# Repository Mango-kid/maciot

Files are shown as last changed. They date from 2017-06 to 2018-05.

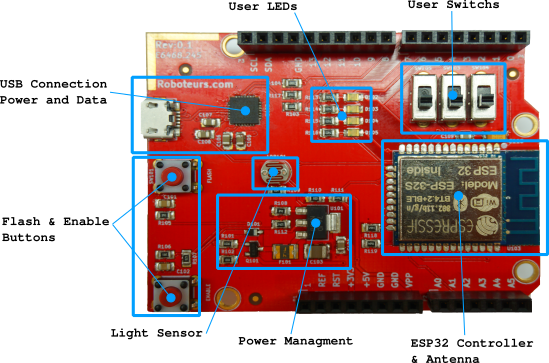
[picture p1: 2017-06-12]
images/layout.png

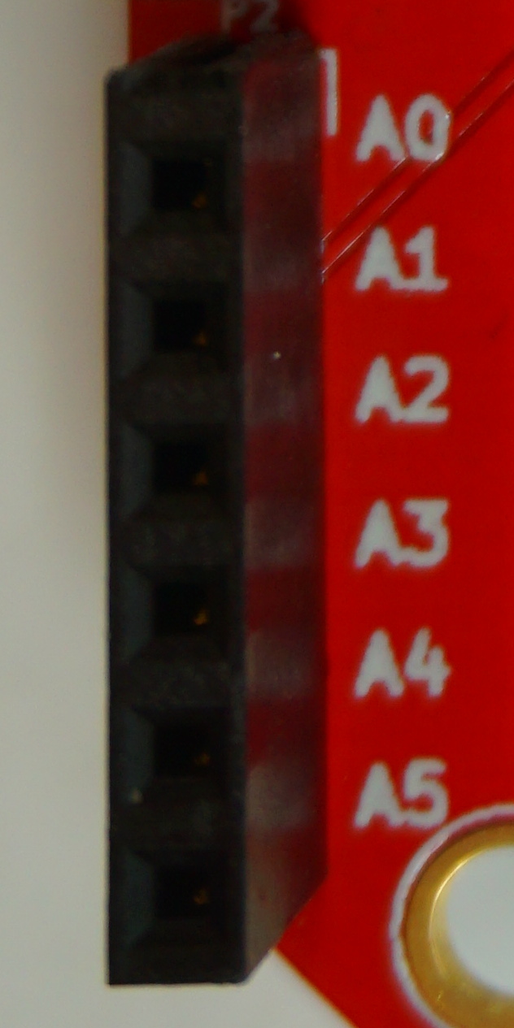
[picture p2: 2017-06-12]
images/pins.JPG

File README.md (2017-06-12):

## Mac-IOT Board

Please check out the [Wiki](https://github.com/Mango-kid/maciot/wiki) for more information on the board design, programming and software setup.  

## Specifications
* bluetooth and(or) wifi capable
* programmable over USB with simple programming IDE
* 4 on board LEDs
* 4 on board switches
* some interactive sensors
* powered by USB or other battery supply
* can use existing Arduino sheild eco-system
***
## License
This project is licensed under the GPLv3 license.

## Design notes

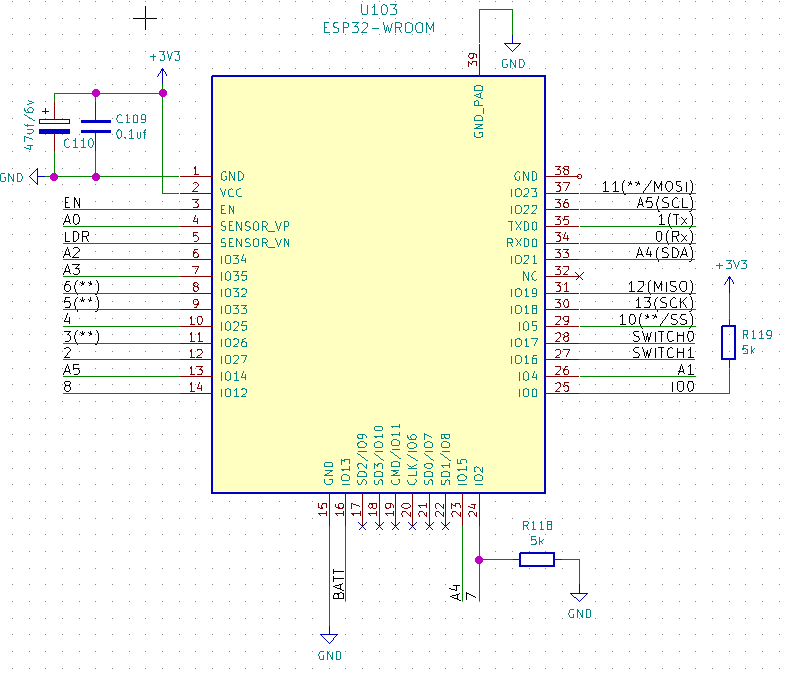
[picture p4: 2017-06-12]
images/sch_esp.png

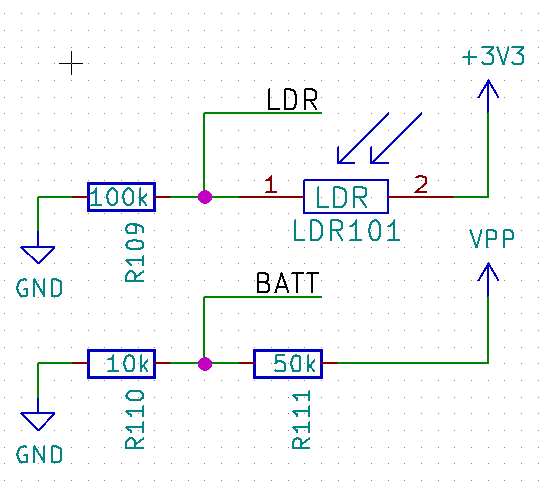
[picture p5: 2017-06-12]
images/sch_sense.png

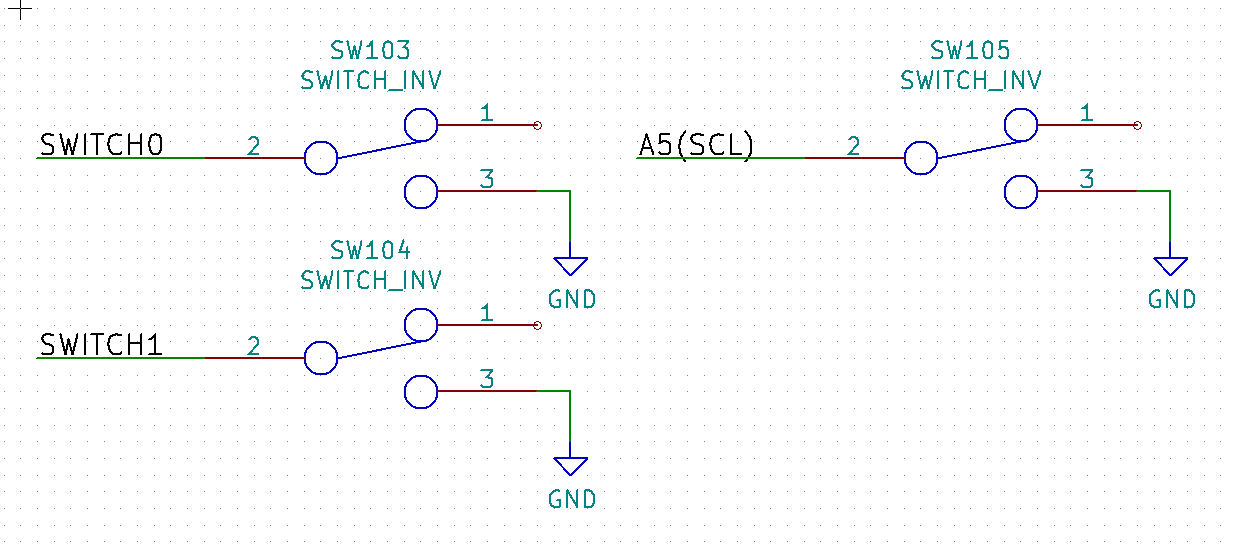
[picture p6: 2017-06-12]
images/sch_switch.png

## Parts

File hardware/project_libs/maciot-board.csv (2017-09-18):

Reference | Value | Footprint | Datasheet | mouser# | digi#
P1 | Power | Socket_Arduino_Uno:Socket_Strip_Arduino_1x08 |  | 474-PRT-09279
P2 | Analog | Socket_Arduino_Uno:Socket_Strip_Arduino_1x06 |  | 474-PRT-09280
P5 | CONN_01X01 | Socket_Arduino_Uno:Arduino_1pin
P6 | CONN_01X01 | Socket_Arduino_Uno:Arduino_1pin
P7 | CONN_01X01 | Socket_Arduino_Uno:Arduino_1pin
P8 | CONN_01X01 | Socket_Arduino_Uno:Arduino_1pin
P4 | Digital | Socket_Arduino_Uno:Socket_Strip_Arduino_1x08 |  | 474-PRT-09279
P3 | Digital | Socket_Arduino_Uno:Socket_Strip_Arduino_1x10 |  | 474-PRT-11376
U101 | LM1117IMPX-ADJ | w_smd_trans:sot223 |  | 926-M1117IMPXADJNOPB
Q101 | Q_PMOS_GDS | w_smd_trans:sot23 |  | 771-PMV48XP215
F101 | FUSE | w_smd_resistors:r_1210 |  | 652-MF-USMF050-2
R102 | 10k | w_smd_resistors:r_0805 |  | ERJ-6GEYJ103V
R101 | 100 | w_smd_resistors:r_0805 |  | ERJ-6ENF1000V
D101 | BAT60 | w_smd_diode:sod323 |  | 726-BAT60AE6327HTSA1
R108 | 390 | w_smd_resistors:r_0805 |  | ERJ-6GEYJ391V
R112 | 240 | w_smd_resistors:r_0805 |  | ERJ-6GEYJ241V
C103 | 10uf | w_smd_cap:c_1210 |  | 77-VJ1210V106ZXJTBC
C104 | 0.1uf | w_smd_cap:c_0805 |  | 81-GCM21BR71H104KA37
U102 | CP2102 | Housings_DFN_QFN:QFN-28-1EP_5x5mm_Pitch0.5mm |  | 634-CP2102-GM
P101 | USB_OTG | w_conn_pc:conn_usb_B_micro_smd |  | 10118192-0001LF
C107 | 0.1uf | w_smd_cap:c_0805 |  | 81-GCM21BR71H104KA40
C108 | 0.1uf | w_smd_cap:c_0805 |  | 81-GCM21BR71H104KA41
C106 | 0.1uf | w_smd_cap:c_0805 |  | 81-GCM21BR71H104KA39
C105 | 0.1uf | w_smd_cap:c_0805 |  | 81-GCM21BR71H104KA38
R117 | 390 | w_smd_resistors:r_0805 |  | ERJ-6GEYJ391V
U103 | ESP32-WROOM | project_foot:ESP32-WROOM
C109 | 0.1uf | w_smd_cap:c_0805 |  | 81-GCM21BR71H104KA42
P102 | TST | Measurement_Points:Measurement_Point_Round-SMD-Pad_Small
P103 | TST | Measurement_Points:Measurement_Point_Round-SMD-Pad_Small
P104 | TST | Measurement_Points:Measurement_Point_Round-SMD-Pad_Small
P105 | TST | Measurement_Points:Measurement_Point_Round-SMD-Pad_Small
P106 | TST | Measurement_Points:Measurement_Point_Round-SMD-Pad_Small
P107 | TST | Measurement_Points:Measurement_Point_Round-SMD-Pad_Small
P108 | TST | Measurement_Points:Measurement_Point_Round-SMD-Pad_Small
P109 | TST | Measurement_Points:Measurement_Point_Round-SMD-Pad_Small
P110 | TST | Measurement_Points:Measurement_Point_Round-SMD-Pad_Small
P111 | TST | Measurement_Points:Measurement_Point_Round-SMD-Pad_Small
P112 | TST | Measurement_Points:Measurement_Point_Round-SMD-Pad_Small
P113 | TST | Measurement_Points:Measurement_Point_Round-SMD-Pad_Small
LDR101 | LDR |  |  |  | PDV-P8103-ND
R110 | 10k | w_smd_resistors:r_0805 |  | ERJ-6GEYJ103V
R111 | 50k | w_smd_resistors:r_0805 |  | ERJ-6ENF4992V
SW101 | FLASH | w_switch:PCB_PUSH |  | 506-FSM4JAH
SW102 | ENABLE | w_switch:PCB_PUSH |  | 506-FSM4JAH
R105 | 390 | w_smd_resistors:r_0805 |  | ERJ-6GEYJ391V
R106 | 390 | w_smd_resistors:r_0805 |  | ERJ-6GEYJ391V
C101 | 10nf | w_smd_cap:c_0805 |  | 81-GRM40X103K50D
C102 | 10nf | w_smd_cap:c_0805 |  | 81-GRM40X103K50D
D102 | LED | w_smd_leds:Led_0805 |  | 604-AP2012YD
R113 | 390 | w_smd_resistors:r_0805 |  | ERJ-6GEYJ391V
D103 | LED | w_smd_leds:Led_0805 |  | 604-AP2012YD
R114 | 390 | w_smd_resistors:r_0805 |  | ERJ-6GEYJ391V
D104 | LED | w_smd_leds:Led_0805 |  | 604-AP2012YD
R115 | 390 | w_smd_resistors:r_0805 |  | ERJ-6GEYJ391V
D105 | LED | w_smd_leds:Led_0805 |  | 604-AP2012YD
R116 | 390 | w_smd_resistors:r_0805 |  | ERJ-6GEYJ391V
SW103 | SWITCH_INV | project_foot:OS102011MS2QN1 Slide Switch |  | 611-OS102011MS2QN1
R118 | 5k | w_smd_resistors:r_0805 |  | ERJ-6ENF4991V
R119 | 5k | w_smd_resistors:r_0805 |  | ERJ-6ENF4991V
SW104 | SWITCH_INV | project_foot:OS102011MS2QN1 Slide Switch |  | 611-OS102011MS2QN1
R107 | 12k | w_smd_resistors:r_0805 |  | ERJ-6GEYJ123V
SW105 | SWITCH_INV | project_foot:OS102011MS2QN1 Slide Switch |  | 611-OS102011MS2QN1
R103 | 0 | w_smd_resistors:r_0805 |  | ERJ-6GEY0R00V
R104 | 0 | w_smd_resistors:r_0805 |  | ERJ-6GEY0R00V
C110 | 47uf/6v | w_smd_cap:c_1206 |  | TAJA476K006SNJV
FD1 | TEST_1P | Fiducials:Fiducial_1mm_Dia_2.54mm_Outer_CopperTop
FD2 | TEST_1P | Fiducials:Fiducial_1mm_Dia_2.54mm_Outer_CopperTop
FD3 | TEST_1P | Fiducials:Fiducial_1mm_Dia_2.54mm_Outer_CopperTop
D1 | LED | w_smd_leds:Led_0805 |  | 604-AP2012YD
R1 | 390 | w_smd_resistors:r_0805 |  | ERJ-6GEYJ391V
R2 | 0 | w_smd_resistors:r_0805 |  | ERJ-6GEY0R00V
R3 | 10k | w_smd_resistors:r_0805 |  | ERJ-6GEYJ103V

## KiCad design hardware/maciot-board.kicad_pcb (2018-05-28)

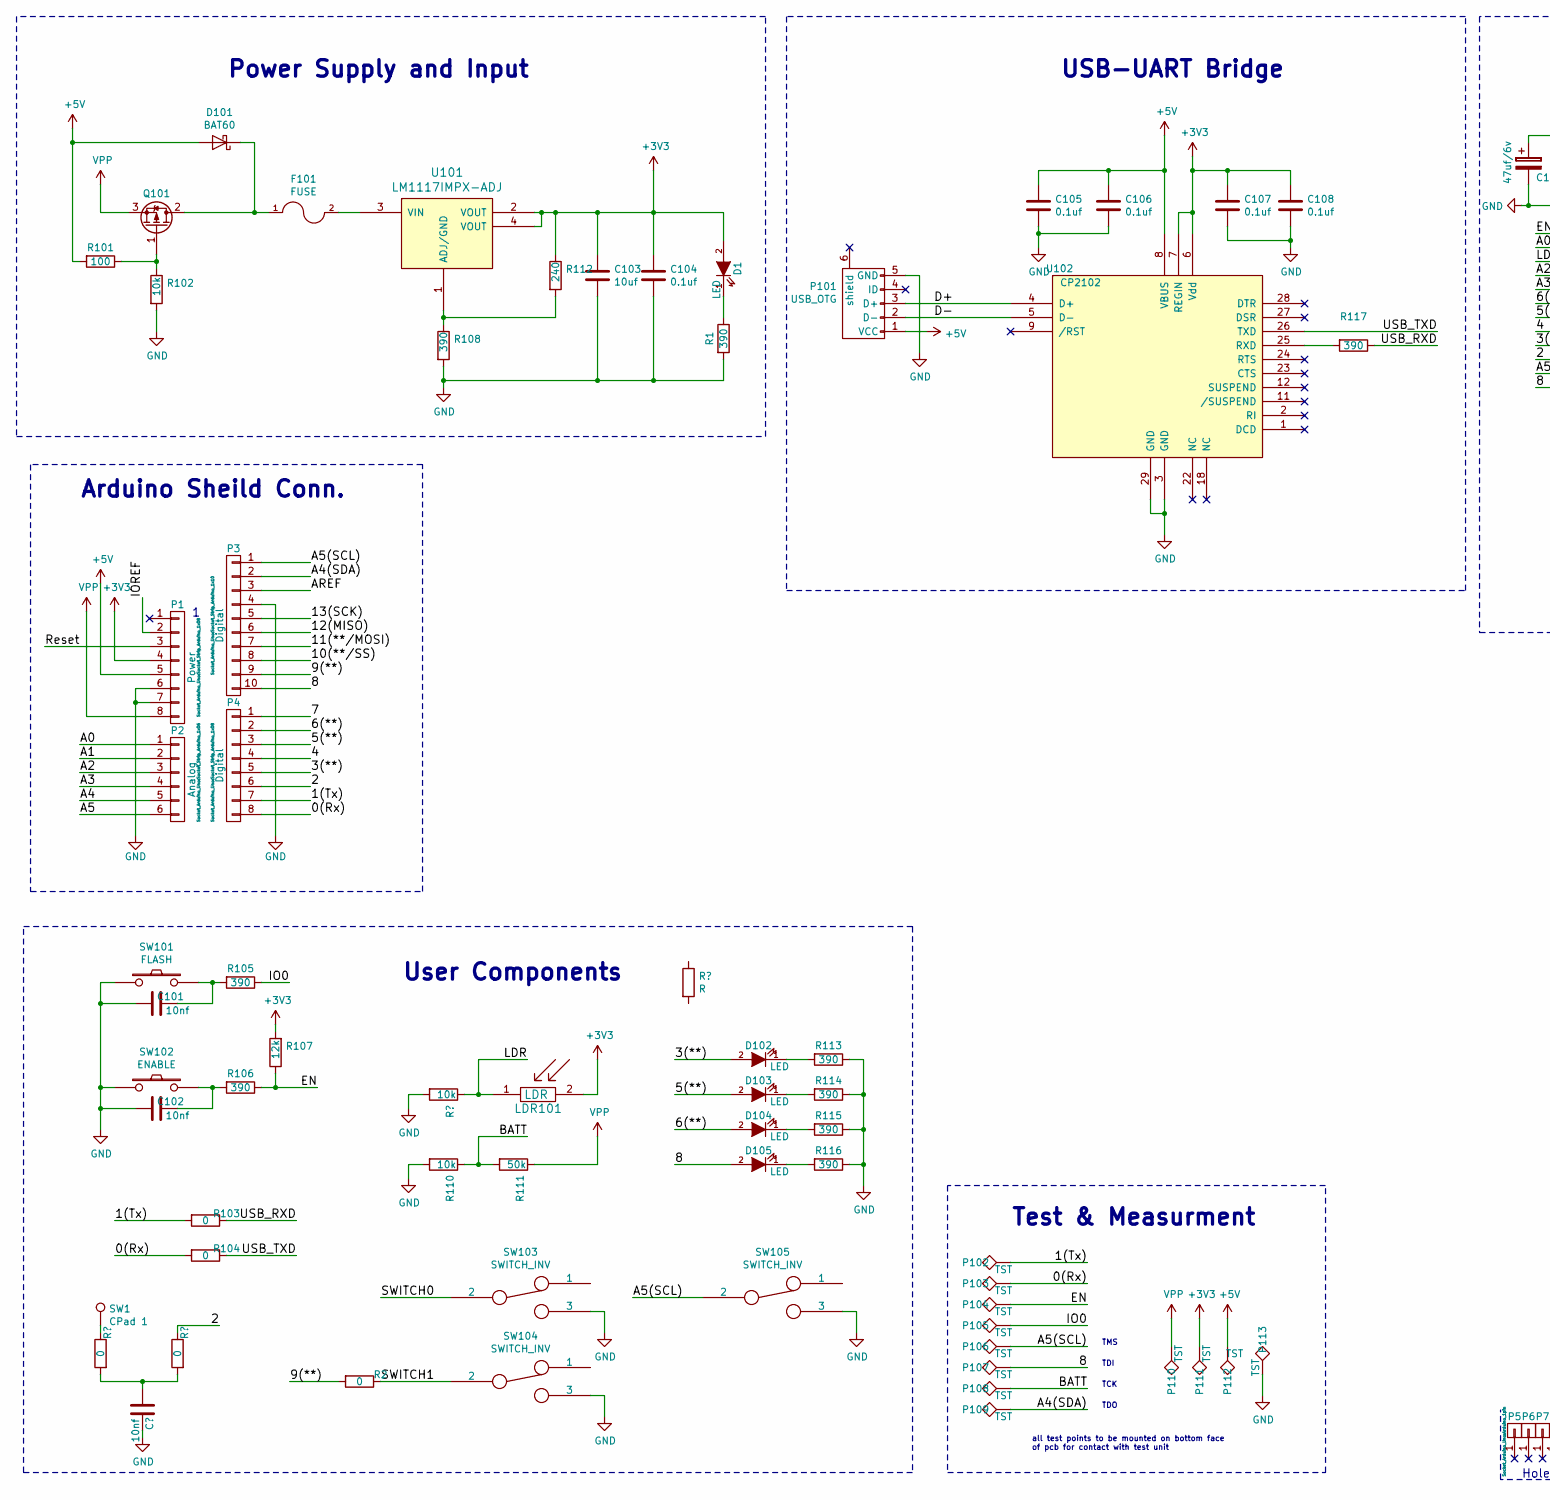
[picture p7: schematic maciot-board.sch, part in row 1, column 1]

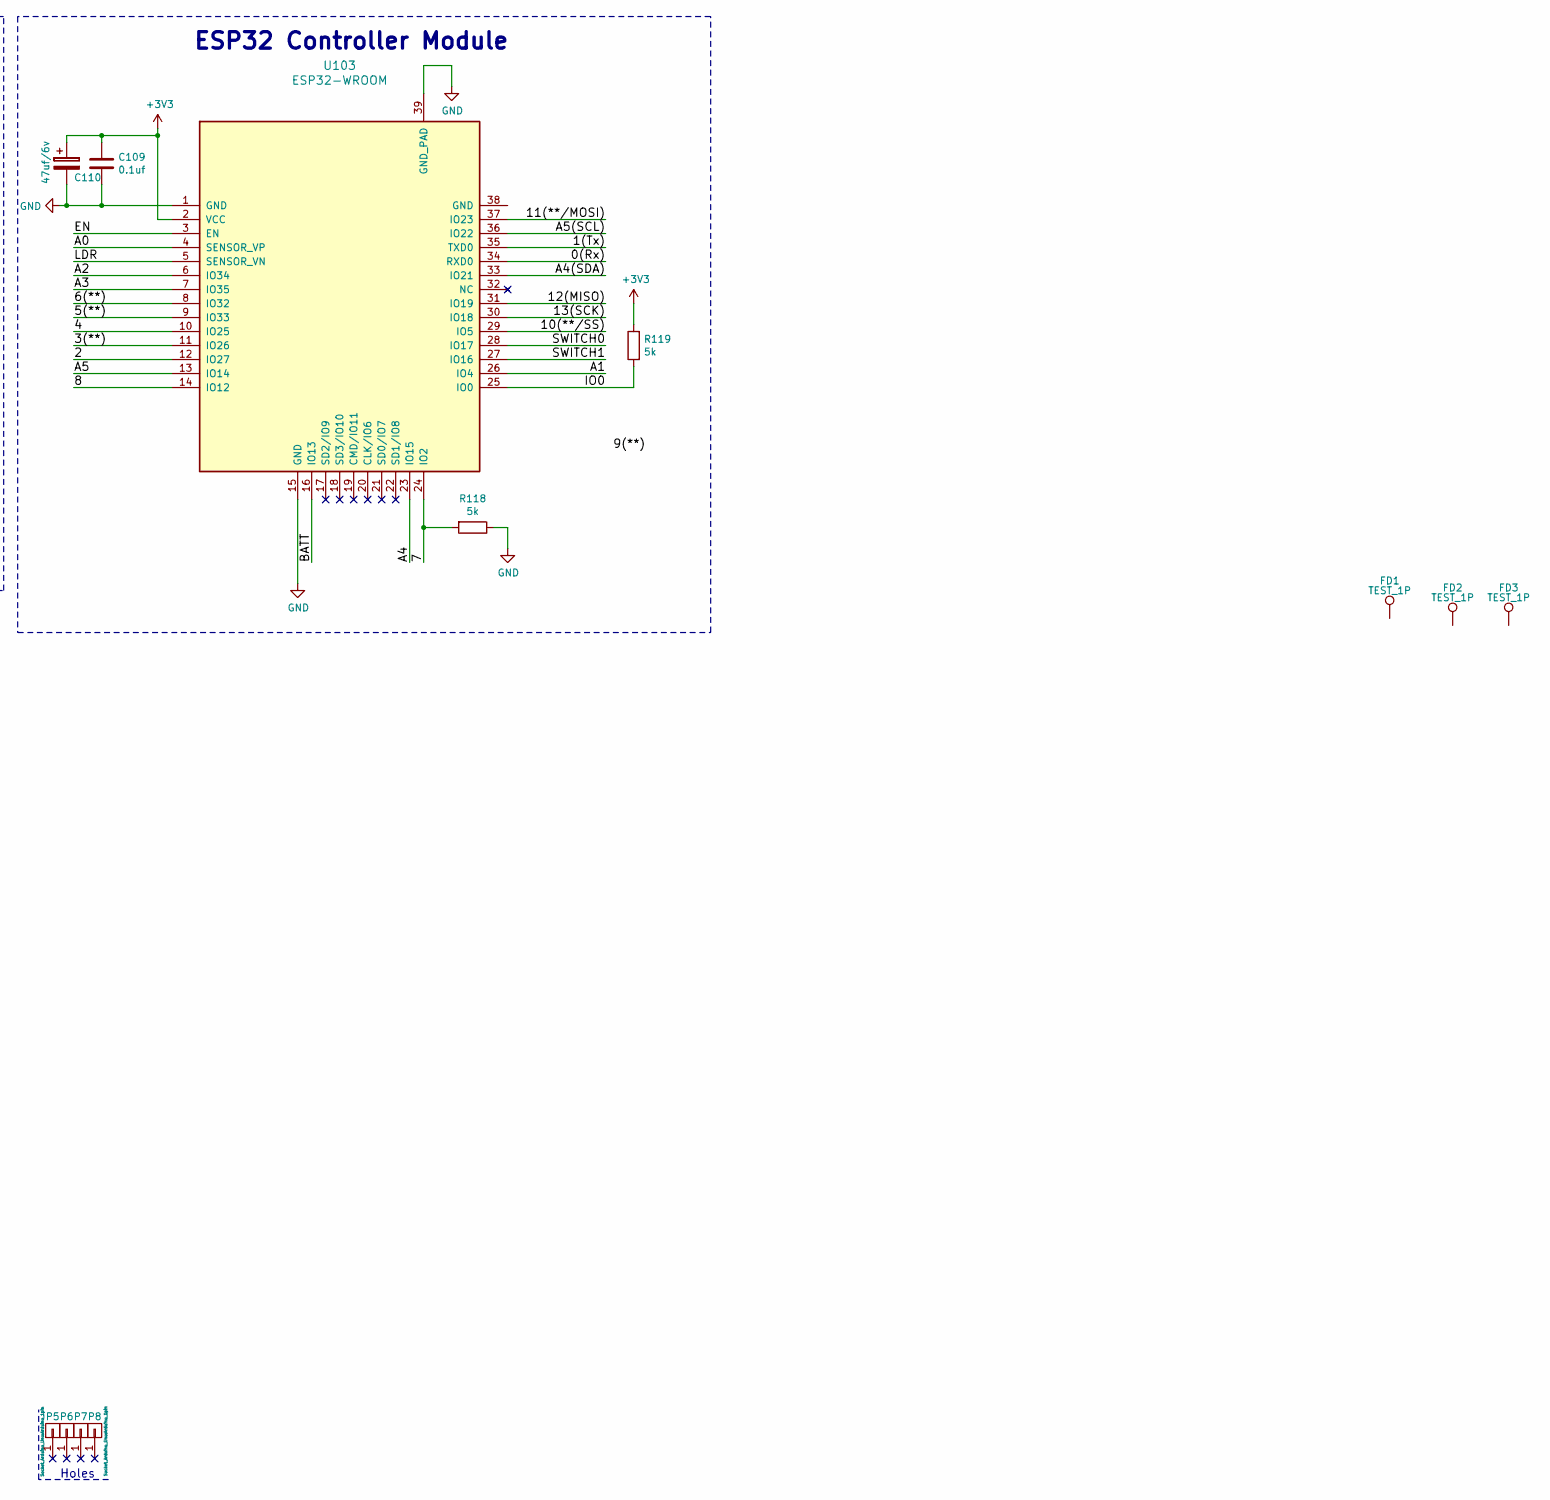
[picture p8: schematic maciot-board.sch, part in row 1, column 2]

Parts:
C101, C102: 10nf; c_0805; mouser# 81-GRM40X103K50D
C103: 10uf; c_1210; mouser# 77-VJ1210V106ZXJTBC
C104: 0.1uf; c_0805; mouser# 81-GCM21BR71H104KA37
C105: 0.1uf; c_0805; mouser# 81-GCM21BR71H104KA38
C106: 0.1uf; c_0805; mouser# 81-GCM21BR71H104KA39
C107: 0.1uf; c_0805; mouser# 81-GCM21BR71H104KA40
C108: 0.1uf; c_0805; mouser# 81-GCM21BR71H104KA41
C109: 0.1uf; c_0805; mouser# 81-GCM21BR71H104KA42
C110: 47uf/6v; c_1206; mouser# TAJA476K006SNJV
D1, D102, D103, D104, D105: LED; Led_0805; mouser# 604-AP2012YD
D101: BAT60; sod323; mouser# 726-BAT60AE6327HTSA1
F101: FUSE; r_1210; mouser# 652-MF-USMF050-2
FD1, FD2, FD3: TEST_1P; Fiducial_1mm_Dia_2.54mm_Outer_CopperTop
LDR101: LDR; digi# PDV-P8103-ND
P1: Power; Socket_Strip_Arduino_1x08; mouser# 474-PRT-09279
P2: Analog; Socket_Strip_Arduino_1x06; mouser# 474-PRT-09280
P3: Digital; Socket_Strip_Arduino_1x10; mouser# 474-PRT-11376
P4: Digital; Socket_Strip_Arduino_1x08; mouser# 474-PRT-09279
P5, P6, P7, P8: CONN_01X01; Arduino_1pin
P101: USB_OTG; conn_usb_B_micro_smd; mouser# 10118192-0001LF
P102, P103, P104, P105, P106, P107, P108, P109, P110, P111, P112, P113: TST; Measurement_Point_Round-SMD-Pad_Small
Q101: Q_PMOS_GDS; sot23; mouser# 771-PMV48XP215
R1, R105, R106, R108, R113, R114, R115, R116, R117: 390; r_0805; mouser# ERJ-6GEYJ391V
R2, R103, R104: 0; r_0805; mouser# ERJ-6GEY0R00V
R101: 100; r_0805; mouser# ERJ-6ENF1000V
R102, R110: 10k; r_0805; mouser# ERJ-6GEYJ103V
R107: 12k; r_0805; mouser# ERJ-6GEYJ123V
R111: 50k; r_0805; mouser# ERJ-6ENF4992V
R112: 240; r_0805; mouser# ERJ-6GEYJ241V
R118, R119: 5k; r_0805; mouser# ERJ-6ENF4991V
SW1: CPad 1
SW101: FLASH; PCB_PUSH; mouser# 506-FSM4JAH
SW102: ENABLE; PCB_PUSH; mouser# 506-FSM4JAH
SW103, SW104, SW105: SWITCH_INV; OS102011MS2QN1 Slide Switch; mouser# 611-OS102011MS2QN1
U101: LM1117IMPX-ADJ; sot223; mouser# 926-M1117IMPXADJNOPB
U102: CP2102; QFN-28-1EP_5x5mm_Pitch0.5mm; mouser# 634-CP2102-GM
U103: ESP32-WROOM

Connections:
+3V3: C103.1, C104.1, C107.1, C108.1, C109.1, C110.1, D1.2 (A), LDR101.2, P1.4, P111.1, R107.2, R112.1, R119.2, U101.2 (VOUT), U101.4 (VOUT), U102.6 (Vdd), U102.7 (REGIN), U103.2 (VCC)
+5V: C105.1, C106.1, D101.2 (A), P1.5, P101.1 (VCC), P112.1, R101.2, U102.8 (VBUS)
/0(Rx): P4.8, P103.1, R104.2, U103.34 (RXD0)
/1(Tx): P4.7, P102.1, R103.2, U103.35 (TXD0)
/2: P4.6, U103.12 (IO27); also elsewhere on the board
/3(**): D102.2 (A), P4.5, U103.11 (IO26)
/4: P4.4, U103.10 (IO25)
/5(**): D103.2 (A), P4.3, U103.9 (IO33)
/6(**): D104.2 (A), P4.2, U103.8 (IO32)
/7: P4.1, R118.2, U103.24 (IO2)
/8: D105.2 (A), P3.10, P107.1, U103.14 (IO12)
/9(**): P3.9, R2.2
/10(**/SS): P3.8, U103.29 (IO5)
/11(**/MOSI): P3.7, U103.37 (IO23)
/12(MISO): P3.6, U103.31 (IO19)
/13(SCK): P3.5, U103.30 (IO18)
/A0: P2.1, U103.4 (SENSOR_VP)
/A1: P2.2, U103.26 (IO4)
/A2: P2.3, U103.6 (IO34)
/A3: P2.4, U103.7 (IO35)
/A4: P2.5, U103.23 (IO15)
/A4(SDA): P3.2, P109.1, U103.33 (IO21)
/A5: P2.6, U103.13 (IO14)
/A5(SCL): P3.1, P106.1, SW105.2, U103.36 (IO22)
/AREF: P3.3
/BATT: P108.1, R110.1, R111.2, U103.16 (IO13)
/D+: P101.3 (D+), U102.4 (D+)
/D-: P101.2 (D-), U102.5 (D-)
/EN: P104.1, R106.1, R107.1, U103.3 (EN)
/IO0: P105.1, R105.1, R119.1, U103.25 (IO0)
/IOREF: P1.2
/LDR: LDR101.1, U103.5 (SENSOR_VN); also elsewhere on the board
/Reset: P1.3
/SWITCH0: SW103.2, U103.28 (IO17)
/SWITCH1: R2.1, SW104.2, U103.27 (IO16)
/USB_RXD: R103.1, R117.1
/USB_TXD: R104.1, U102.26 (TXD)
GND: C101.2, C102.2, C103.2, C104.2, C105.2, C106.2, C107.2, C108.2, C109.2, C110.2, P1.6, P1.7, P3.4, P101.5 (GND), P113.1, R1.2, R102.2, R108.2, R110.2, R113.1, R114.1, R115.1, R116.1, R118.1, SW101.1, SW102.1, SW103.3, SW104.3, SW105.3, U102.3 (GND), U102.29 (GND), U103.1 (GND), U103.15 (GND), U103.39 (GND_PAD); also elsewhere on the board
unnamed: C101.1, R105.2, SW101.2
unnamed: C102.1, R106.2, SW102.2
unnamed: D1.1 (K), R1.1
unnamed: D101.1 (K), F101.1, Q101.2 (D)
unnamed: D102.1 (K), R113.2
unnamed: D103.1 (K), R114.2
unnamed: D104.1 (K), R115.2
unnamed: D105.1 (K), R116.2
unnamed: F101.2, U101.3 (VIN)
unnamed: Q101.1 (G), R101.1, R102.1
unnamed: R108.1, R112.2, U101.1 (ADJ/GND)
unnamed: R117.2, U102.25 (RXD)
unnamed: U102.10 (NC), U102.13 (NC), U102.14 (NC), U102.15 (NC), U102.16 (NC), U102.17 (NC), U102.19 (NC), U102.20 (NC), U102.21 (NC), U102.22 (NC)
VPP: P1.8, P110.1, Q101.3 (S), R111.1

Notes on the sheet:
Holes
Power Supply and Input
USB-UART Bridge
TMS
TDI
TCK
TDO
Test & Measurment
all test points to be mounted on bottom face of pcb for contact with test unit
ESP32 Controller Module
User Components
Arduino Sheild Conn.

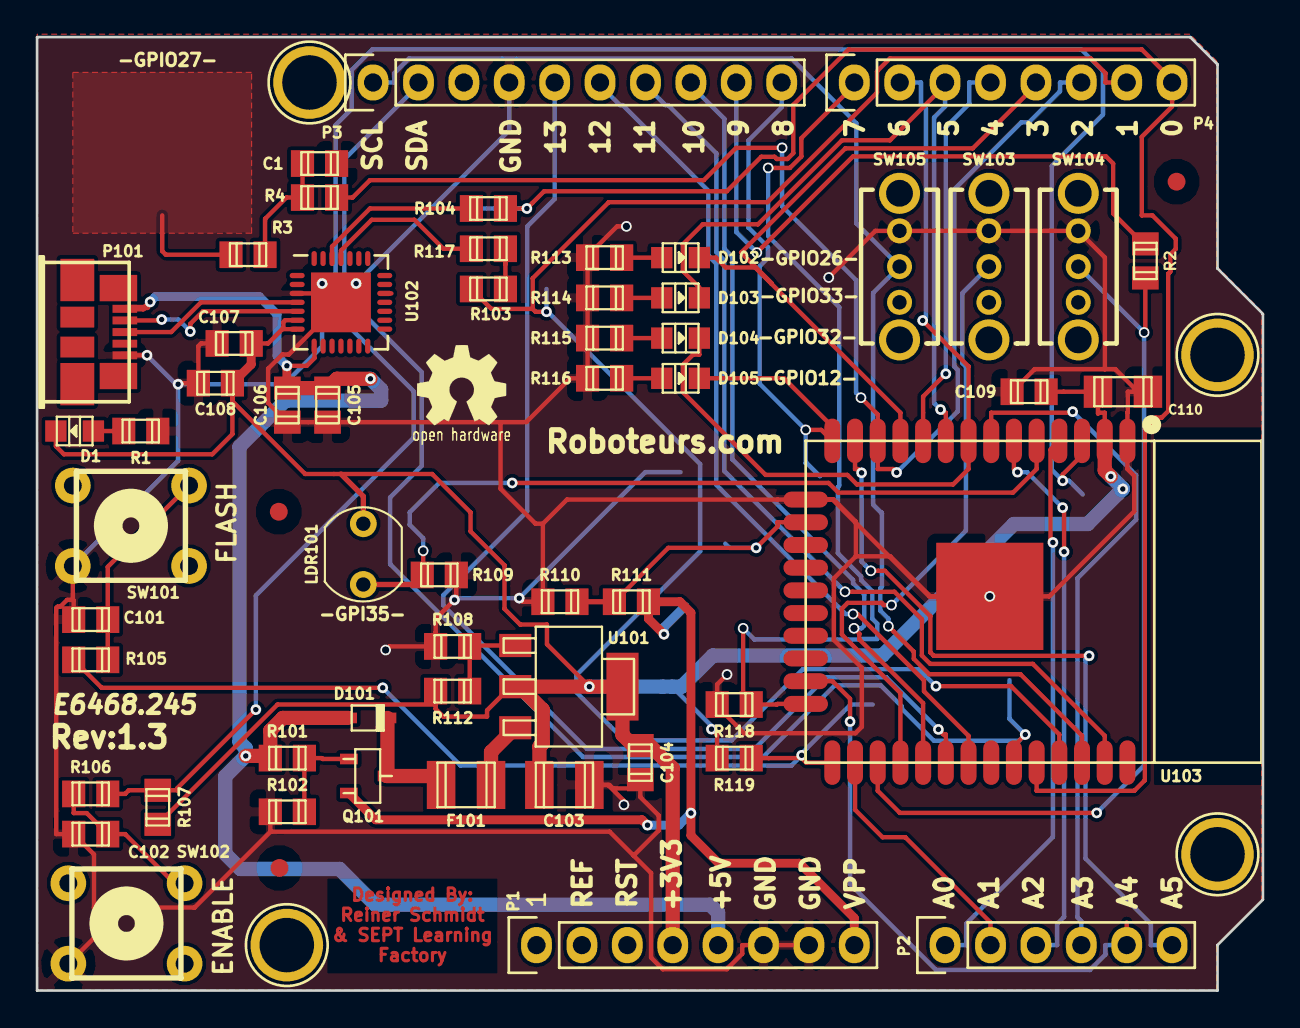
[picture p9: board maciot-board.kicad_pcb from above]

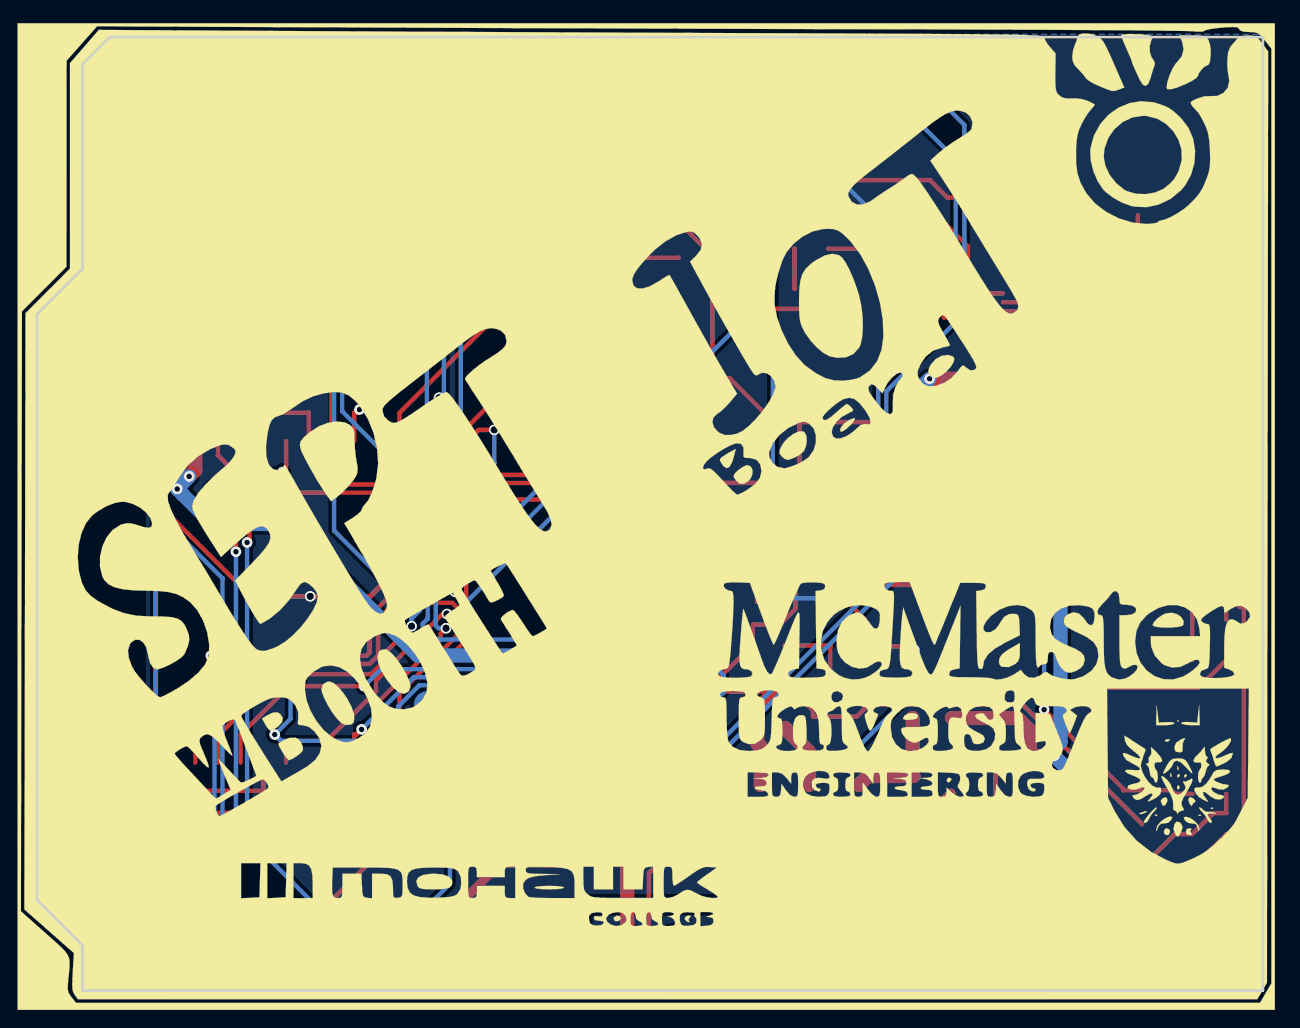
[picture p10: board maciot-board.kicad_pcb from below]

Board: 2 copper layers, 68.6 x 53.3 mm, 75 parts (12 on the bottom side), 50 nets.

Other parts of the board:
C1: 10nf; c_0805
R3, R4: 0; r_0805
R109: 100k; r_0805

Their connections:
/2: R4.2; also elsewhere on the board
/LDR: R109.1; also elsewhere on the board
GND: C1.1, R109.2; also elsewhere on the board
unnamed: C1.2, R3.1, R4.1

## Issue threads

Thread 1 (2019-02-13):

Cannot Run Bluetooth Scanner on MacIoT Board

mso797, 2019-02-13:
Hi,

I'm trying to run the following code on my MacIoT board, but I keep on running into an error.
/*
   Based on Neil Kolban example for IDF: https://github.com/nkolban/esp32-snippets/blob/master/cpp_utils/tests/BLE%20Tests/SampleScan.cpp
   Ported to Arduino ESP32 by Evandro Copercini
*/

#include <BLEDevice.h>
#include <BLEUtils.h>
#include <BLEScan.h>
#include <BLEAdvertisedDevice.h>

int scanTime = 5; //In seconds
BLEScan* pBLEScan;

class MyAdvertisedDeviceCallbacks: public BLEAdvertisedDeviceCallbacks {
    void onResult(BLEAdvertisedDevice advertisedDevice) {
      Serial.printf("Advertised Device: %s \n", advertisedDevice.toString().c_str());
    }
};

void setup() {
  Serial.begin(115200);
  Serial.println("Scanning...");

  BLEDevice::init("");
  pBLEScan = BLEDevice::getScan(); //create new scan
  pBLEScan->setAdvertisedDeviceCallbacks(new MyAdvertisedDeviceCallbacks());
  pBLEScan->setActiveScan(true); //active scan uses more power, but get results faster
  pBLEScan->setInterval(100);
  pBLEScan->setWindow(99);  // less or equal setInterval value
}

void loop() {
  // put your main code here, to run repeatedly:
  BLEScanResults foundDevices = pBLEScan->start(scanTime, false);
  Serial.print("Devices found: ");
  Serial.println(foundDevices.getCount());
  Serial.println("Scan done!");
  pBLEScan->clearResults();   // delete results fromBLEScan buffer to release memory
  delay(2000);
}

Here is the error that I am getting: #error "C++ exception handling must be enabled within make menuconfig. See Compiler Options > Enable C++ Exceptions."

From my understanding, the Arduino IDE does not have this option.

Any help would be greatly appreciated!

Mango-kid, 2019-02-13:
This error is not an issue related to the MacIot board. I would look into
the Arduino port for the ESP32 device.

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

mso797, 2019-02-13:
> This error is not an issue related to the MacIot board. I would look into the Arduino port for the ESP32 device.
> […](#)
> On Tue, Feb 12, 2019 at 9:18 PM mso797 ***@***.***> wrote: Hi, I'm trying to run the following code on my MacIoT board, but I keep on running into an error. /* Based on Neil Kolban example for IDF: https://github.com/nkolban/esp32-snippets/blob/master/cpp_utils/tests/BLE%20Tests/SampleScan.cpp Ported to Arduino ESP32 by Evandro Copercini */ #include <BLEDevice.h> #include <BLEUtils.h> #include <BLEScan.h> #include <BLEAdvertisedDevice.h> int scanTime = 5; //In seconds BLEScan* pBLEScan; class MyAdvertisedDeviceCallbacks: public BLEAdvertisedDeviceCallbacks { void onResult(BLEAdvertisedDevice advertisedDevice) { Serial.printf("Advertised Device: %s \n", advertisedDevice.toString().c_str()); } }; void setup() { Serial.begin(115200); Serial.println("Scanning..."); BLEDevice::init(""); pBLEScan = BLEDevice::getScan(); //create new scan pBLEScan->setAdvertisedDeviceCallbacks(new MyAdvertisedDeviceCallbacks()); pBLEScan->setActiveScan(true); //active scan uses more power, but get results faster pBLEScan->setInterval(100); pBLEScan->setWindow(99); // less or equal setInterval value } void loop() { // put your main code here, to run repeatedly: BLEScanResults foundDevices = pBLEScan->start(scanTime, false); Serial.print("Devices found: "); Serial.println(foundDevices.getCount()); Serial.println("Scan done!"); pBLEScan->clearResults(); // delete results fromBLEScan buffer to release memory delay(2000); } Here is the error that I am getting: #error "C++ exception handling must be enabled within make menuconfig. See Compiler Options > Enable C++ Exceptions." From my understanding, the Arduino IDE does not have this option. Any help would be greatly appreciated! — You are receiving this because you are subscribed to this thread. Reply to this email directly, view it on GitHub <#1>, or mute the thread <https://github.com/notifications/unsubscribe-auth/AFfhxj4Qn3eZqHwMu_g8_0fEStWNy4NWks5vM3X3gaJpZM4a4c_i> .

Hi

mso797, 2019-02-13:
Hi sorry, can you elaborate by the Arduino port? Do you mean the serial port?

Mango-kid, 2019-02-13:
Sorry. I mean the Arduino software for ESP32. This can also be found on
GitHub. You can post an issue their. It will have its own repository.

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

mso797, 2019-02-13:
The solution I find online is to use the esspressif ide(esp-idf) instead of the arduino ide. In that gui, there is the option "Compiler Options > Enable C++ Exceptions".

But from my understanding the MacIoT board exists for arduino only. I was wondering if there was a way I could use the MacIoT board in esp-idf instead of arduino ide?

Mango-kid, 2019-02-13:
It will also work with the Esspresif IDE. You will have to upload code
manually and also have some knowledge of the pins. If you are interested in
programming it is a worthy pursuit, however there will be a learning curve.

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

mso797, 2019-02-13:
Ok, that's good to know. We're trying to setup a ble beacon demo.
The MacIoT boards work fine as ble beacons, but I cannot get one to work as a scanner.
As of right now, my plan is to just use a different board as the scanner.

I just want to make sure that there is no existing code or example where you use the MacIoT board as a BLE scanner? If there is, could you point me to it?

Mango-kid, 2019-02-13:
Sorry now that I know of. Some other students had worked with BLE before
but I am not sure who.

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

mso797, 2019-02-13:
Ok no worries, thanks for your help!

Closed 2019-02-13.

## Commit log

2017-06-12 inital commit
    [maciot-board.csv, maciot-board.kicad_pcb, maciot-board.sch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]
2017-06-12 updated board name
2017-09-18 simple updates
    [maciot-board.csv, maciot-board.kicad_pcb, maciot-board.sch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]
2018-05-28 added cap pad
    [maciot-board.kicad_pcb, maciot-board.sch]
